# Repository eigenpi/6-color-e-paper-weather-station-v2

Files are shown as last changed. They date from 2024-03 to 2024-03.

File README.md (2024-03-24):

# E-Paper Weather Station V2

## Description

This is a modified version of an existing project of Nick Koumaris. 
The project uses a 6 color e-paper display (600x448 pixels) from InkPlate 
(now Soldered) to display the weather forecast and indoor temperature, humidity, 
and pressure. His original project is availbale here: 

[Arduino Color E Paper Weather Station](https://github.com/educ8s/Arduino-Color-E-Paper-Weather-Station)

The main changes I made are the following:

1. I replaced writing data to EEPROM with writing into the SD-Card. The InkPlate 
display  - which is really a small development board with an Espressif ESP32-WROVER-E
microcontroller and a micro-SD card slot - can use a micro-SD card as well.
The reason for not writing into EEPROM is that a typical EEPROM memory has a 
specified life of 100,000 write/erase cycles; and, I have read before that this
number might be actually smaller. So, given that the initial project writes once per hour
data into EEPROM (that makes 24 h x 365 days = 8,760 times/year), we risk of 
losing the InkPlate display in 10 years or less. Writing into the micro-SD card
might be a better approach, as replacing the micro-SD card woudl be a matter of
just a few dollars. Replacing the InkPlate e-paper display would cost around $130.

2. I retrieve from openweathermap.org also the temperature outside and print it
on the e-paper display too, in addition to the weather forecast. This is done every
four hours now (original project does it every 6 hours).

3. In addition, I print on the e-paper display: i) the name of the city, at the top 
and ii) the date and time of last update of the forecast, at the bottom of the display.

4. I reorganized a bit the code in the main program. I also created a 3D printed 
half-enclosure to protect the indoor sensors - this also helps making the display 
more stable.

This is how the final design looks like:

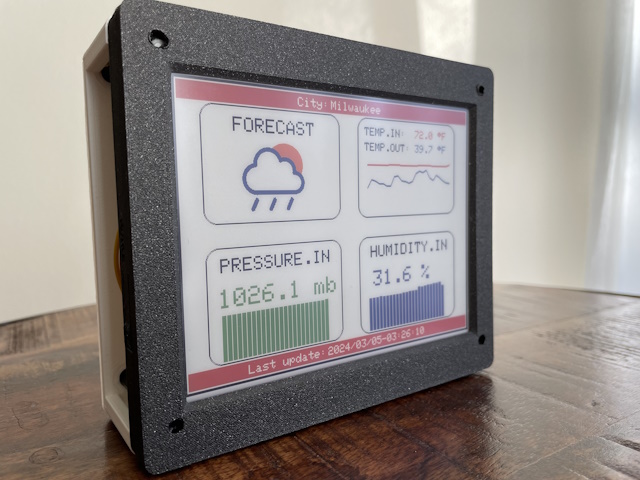
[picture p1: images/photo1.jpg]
photo1 is overall design


## Basic Steps to Replicate this Project

### Step 1

Connect the pressure sensor (BMP180) and the himidity and temperature sensor (DHT22)
to a small breadboard. Then, glue with the help of double side sticky tape the breadboard
to the back of the InkPlate original 3D printed case. Use jumper wire to connect the sensors
to the selected pins of the InPlate board - as shown in the figure below (and as 
also discussed in the comments inside the code). You will have to cut a portion of the
back side of the InkPlate original 3D printed case to be able to attach teh jumper wires.
Connect also the battery to the dedicated connector on the board.

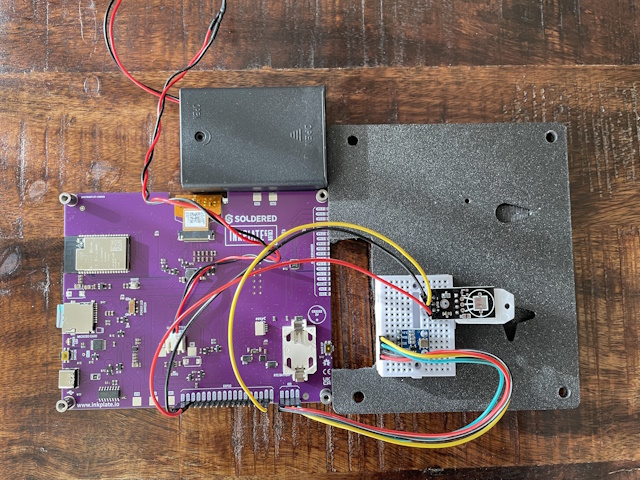
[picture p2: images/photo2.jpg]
photo2 shows connection on the back side


### Step 2

Insert a micro-SD card. Before using the card you must first create several empty .txt files
and save them on the card. You should do that on your own laptop/computer, which I assume has 
a card reader. The empty files that you must create should have the following names:
data.txt, weatherid.txt, city.txt, dateandtime.txt, and bootupcount.txt.

### Step 3 (Optional)

Using a 3D printer, print the additional half-enclosure, which then can be easily attached
with the help of plastic screws on the the InkPlate board (will require driling holes into
the four corners of the back side of the InkPlate original 3D printed case).
The photo below shows the project after that is done. 

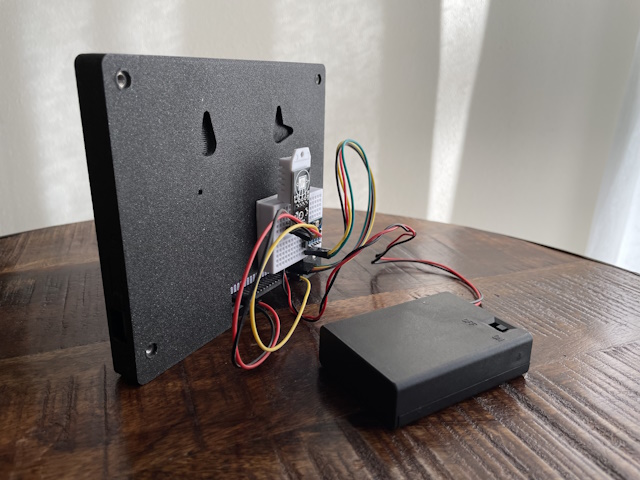
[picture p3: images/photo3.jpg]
photo3 shows holes in the original case


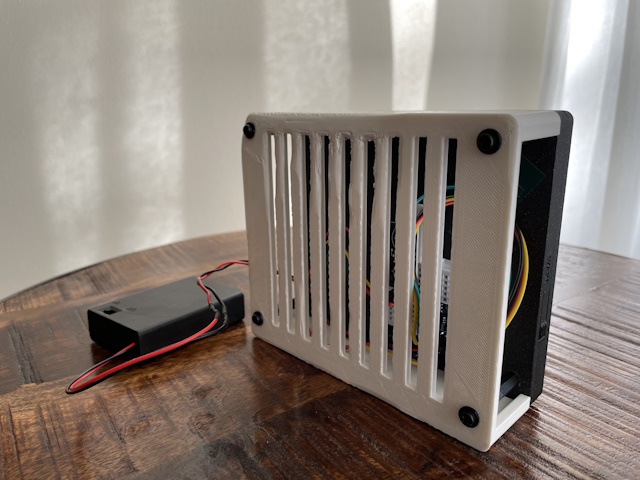
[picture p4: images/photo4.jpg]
photo4 shows 3D printed half-enclosure


### Step 4

Open the Arduino sketch in your Arduino IDE, and edit it to provide your own specific values for:
char *ssid     = "Your-WiFi-Router-Name"; 
char *password = "Your-Password"; 
char *APIKEY   = "Key-You-Get-From-openweathermap";
char *cityID   = "Your-City-Number-ID"; // This is 5263045 for Milwaukee, USA
Then, compile and program the InkPlate/Soldered board. If all good, you should
see the e-paper display showing for the first time your weather forecast.

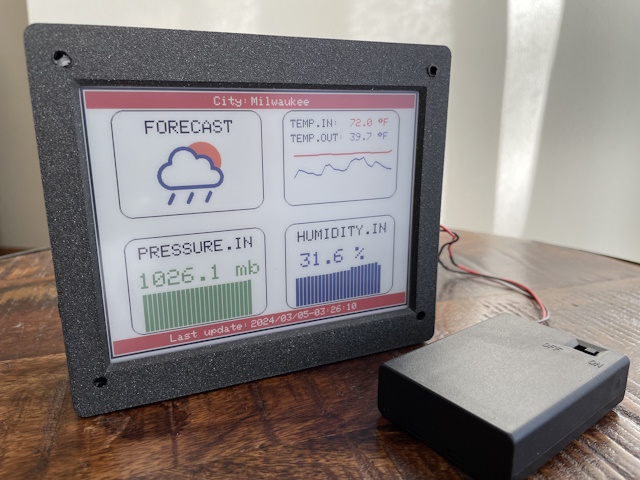
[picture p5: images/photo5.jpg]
photo5 shows the final project again


## Youtube Video

I create a youtube video to showcase this project and highlight some of the main 
aspects about the source code. Check it out here:

[youtube video](https://www.youtube.com/watch?v=4-IhC7Kmzh4)

## Original Design

As I said, this is a modified version of an existing project of Nick Koumaris. 
His original project is availbale here, on github, and on his website: 

1. [Arduino Color E Paper Weather Station - on github](https://github.com/educ8s/Arduino-Color-E-Paper-Weather-Station)

2. [Arduino Color E Paper Weather Station - on Nick's website](https://educ8s.tv/arduino-e-paper-weather-station/)

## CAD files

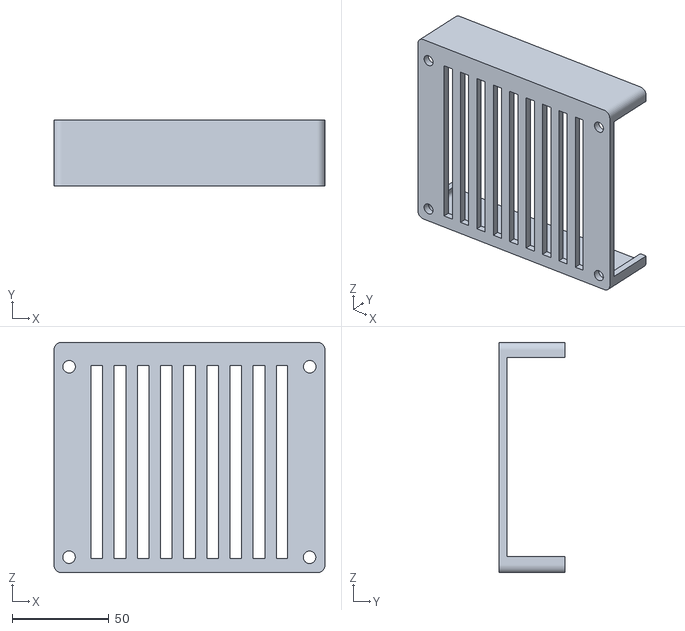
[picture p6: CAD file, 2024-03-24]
3D_printing_enclosure/back_side.stl
140.4 x 34.0 x 119.4

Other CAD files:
3D_printing_enclosure/back_side.f3d

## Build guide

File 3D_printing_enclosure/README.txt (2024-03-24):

Theis is the 3D model of an half-enclosure.
You really need only the .STL file to 3D print it.
It was created with Autodesk Fusion 360.

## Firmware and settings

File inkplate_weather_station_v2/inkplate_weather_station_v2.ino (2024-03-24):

#include "sensors.h"
#include "display.h"
#include "SDCardManager.h"
#include "DataManager.h"
#include "ForecastManager.h"
#include "driver/rtc_io.h" // ESP32 library used for deep sleep and RTC wake up pins

// NOTE: do not use any of the pins 12,13,14,15 of the Inkplate display to
// connect to DHT22 sensor because those pins are used by spi2.begin(14, 12, 13, 15)
// to talk to the SD Card!

#define uS_TO_S_FACTOR 1000000     // Conversion factor from micro seconds to seconds
unsigned int TIME_TO_SLEEP = 3600; // How long ESP32 will be in deep sleep (in seconds)
#define DHTPIN 25                  // Digital pin connected to the DHT sensor
#define DHTTYPE DHT22              // Type of temperature sensor: DHT 22 (AM2302), AM2321;

char *ssid     = "Your-WiFi-Router-Name"; 
char *password = "Your-Password"; 
char *APIKEY   = "Key-You-Get-From-openweathermap";
char *cityID   = "Your-City-Number-ID"; // This is 5263045 for Milwaukee, USA

// sensors is basically a wrapper/host of the two main
// objects that deal with DHT22 and BMP085 sensors;
Sensors sensors(DHTPIN, DHT22);

// basically a wrapper around Inplate display object;
// note that a reference to that display object will
// need to be passed to the SD Card manager class instance next;
Display display; 

// handling writing and reading from the sd card; is
// maybe (unintuitively) done through the Inkplate display instance;
// argument is reference/adress of Inkplate display object;
SDCardManager sd_card( display.get_inkplate_display()); 

// an all-in-one-place container to store 24 values of each 
// displayed variable; will be shifted left every hour; used
// also to display bar-graph plots and other plots on the display;
// also used for writing and reading from sd card;
DataManager all_data_manager; 

// to connect to the WiFi and openweathermap.org
ForecastManager forecast;

///////////////////////////////////////////////////////////////////////////////
//
// setup
//
///////////////////////////////////////////////////////////////////////////////

void setup() 
{
  bool connection_to_wifi_ok = false;
  Serial.begin(115200);
  Serial.println("\n---- Welcome to Weather Station V2.0 ----");

  display.begin();
  Serial.println("Initialized Inkplate display.");

  // read all data from SD Card;
  Serial.println("Reading all data from SD Card...");
  sd_card.loadAllData( all_data_manager); // all indoor and outdoor information;
  sd_card.read_bootupcount_from_sd_card(); // read also separately bootupcount;
  // at this time data manager should have all Old information loaded from sd_card;
  //all_data_manager.printAllData(); // debug;

  // every 4h, get the Weather Forecast Id, outside temperature, and city name;
  // we do it only every 4h to minimize the amount of times we need
  // to connect to the Internet - the WiFi tranceiver consumes power!
  if ( sd_card.get_bootupcount() %4 == 0) {
    Serial.println("Connecting to WiFi...");
    connection_to_wifi_ok = forecast.begin(ssid, password);
    if (connection_to_wifi_ok == true) {
      forecast.getForecast(cityID, APIKEY);
      forecast.get_date_and_time();
      forecast.copy_forecast_to_data_manager( all_data_manager); // incuding dateandtime;
    }
  }

  // every 1h, update the graphs, but only the Indoor sensors
  // will be updated with current sensor readings; the forecast 
  // and outdoor temperature remain as of last connection to wifi,
  // which is done every 4h;
  sensors.begin(); 
  Serial.println(F("Initialized indoor sensors."));
  // read current Indoor sensors: temperature, humidity, pressure;
  Serial.println("Reading indoor sensors...");
  sensors.readIndoorSensors(); 
  // copy new sensor readings to data manager;
  Serial.println("Copy indoor sensor readings to data manager...");
  sensors.copy_current_readings_to_data_manager( all_data_manager);
  // write all data to SD Card;
  // NOTE: important for this to be done after also reading
  // weather forecast from Internet, so that updated information 
  // every 4h is included too;
  Serial.println("Writing all data to SD Card...");
  sd_card.saveAllData( all_data_manager); // write to sd card all information;
  sd_card.incr_and_write_bootupcount_to_sd_card();
  
  // at this time data manager should have all information (arrays
  // of 24 values) updated; some updates happen every 4h, all others
  // are updated every 1h; also, every 1h these data was written into 
  // sd_card too;
  //sensors.print_indoor_sensors_data(); // debug;
  all_data_manager.printAllData(); // debug;

  // update Inkplate display screen;
  display.printUI();
  display.printCityName( all_data_manager.getCityName());
  display.printLastUpdate( all_data_manager.getDateAndTime());
  display.printTemperature( all_data_manager.get_latest_temperature(), all_data_manager.get_latest_temperature_outside());
  display.printHumidity( all_data_manager.get_latest_humidity());
  display.printPressure( all_data_manager.get_latest_pressure());
  display.printTemperatureGraph( all_data_manager.temperature, all_data_manager.temperature_outside);
  display.printPressureGraph( all_data_manager.pressure);
  display.printHumidityGraph( all_data_manager.humidity);
  display.printWeatherIcon( all_data_manager.id);
  display.update();

  // go to sleep every 1h;
  Serial.println("Going to deep sleep now...");
  sleep();

  Serial.println("Setup done!");
}

///////////////////////////////////////////////////////////////////////////////
//
// loop
//
///////////////////////////////////////////////////////////////////////////////

void loop() 
{
  //delay(2000);
  //sensors.readIndoorSensors(true);
}

void sleep() 
{
  // put sd card to sleep too (turns off a transistor?);
  sd_card.place_sd_card_to_sleep();
  // Activate wake-up timer -- wake up after 3600s here
  esp_sleep_enable_timer_wakeup(TIME_TO_SLEEP * uS_TO_S_FACTOR);
  // Put ESP32 into deep sleep. Program stops here.
  esp_deep_sleep_start();
}

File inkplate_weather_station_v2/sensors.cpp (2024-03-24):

#include "sensors.h"
#include "DataManager.h"

Sensors::Sensors(int dht22Pin, uint8_t type) : dht22(dht22Pin, type) 
{
  temperature = 0.0;
  humidity = 0.0;
  pressure = 0.0;
}

void Sensors::begin()
{
  dht22.begin();
  bmp.begin();
}

float Sensors::getTemperature() { return temperature; }
float Sensors::getHumidity() { return humidity; }
float Sensors::getPressure() { return pressure; }

void Sensors::copy_current_readings_to_data_manager(DataManager &data_manager)
{
  data_manager.updateIndoorSensorsData(temperature, humidity, pressure); 
}

void Sensors::readIndoorSensors(bool print_to_serial) 
{
  // (1) Read temperature and humidity; 
  humidity = dht22.readHumidity();
  // Read temperature in Fahrenheit (isFahrenheit = true)
  temperature = dht22.readTemperature(true);

  // (2) Read pressure;
  pressure = bmp.readPressure()/97.5;

  // (3) if debug true, print to serial terminal too;
  if (print_to_serial == true) {
    // (a) check if any reads from DHT22 sensor failed and exit early.
    if (isnan(humidity) || isnan(temperature)) {
      Serial.println(F("ERROR: Failed to read from DHT sensor!"));
    }
    Serial.print(F("Humidity: "));
    Serial.print(humidity);
    Serial.print(F("%  Temperature: "));
    Serial.print(temperature);
    Serial.println(F("°F"));

    // (b) check reading from pressure sensor BMP085 too;
    if (isnan(pressure)) {
      Serial.println(F("ERROR: Failed to read from BMP085 sensor!"));
    }
    Serial.print(F("Pressure: "));
    Serial.print(pressure);
    Serial.println(F(" mb"));
  }
}

void Sensors::print_indoor_sensors_data()
{
  // for debug purposes;
  Serial.print(F("Humidity: "));
  Serial.print(humidity);
  Serial.print(F("%  Temperature: "));
  Serial.print(temperature);
  Serial.println(F(" °F"));
  Serial.print(F("Pressure: "));
  Serial.print(pressure);
  Serial.println(F(" mb"));
}
